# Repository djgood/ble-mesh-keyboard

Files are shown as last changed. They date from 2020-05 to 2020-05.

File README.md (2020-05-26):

# BLE Split Keyboard Project

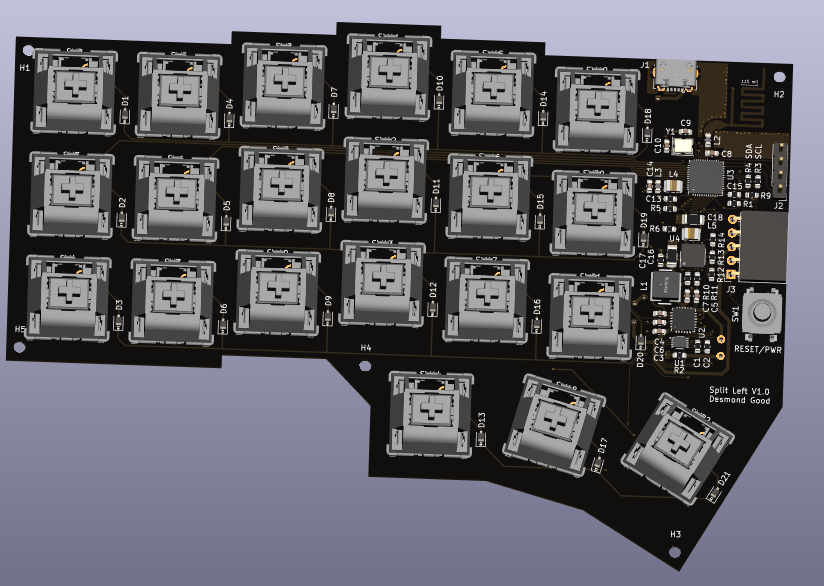
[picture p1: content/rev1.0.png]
rev1.0 layout


## Project Structure

    ├── doc             # datasheets, app notes, references
    ├── firmware        # Zephyr project files (TODO)
    ├── hardware        # KiCAD project files 

## Block Diagram

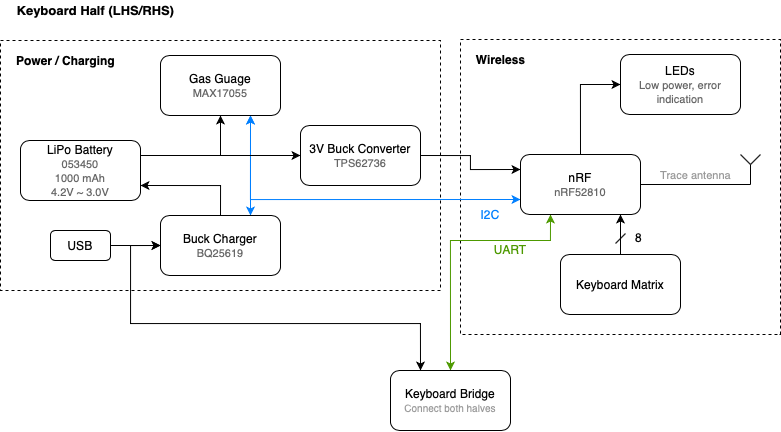
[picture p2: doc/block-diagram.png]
block diagram


View this project on [CADLAB.io](https://cadlab.io/project/22910).

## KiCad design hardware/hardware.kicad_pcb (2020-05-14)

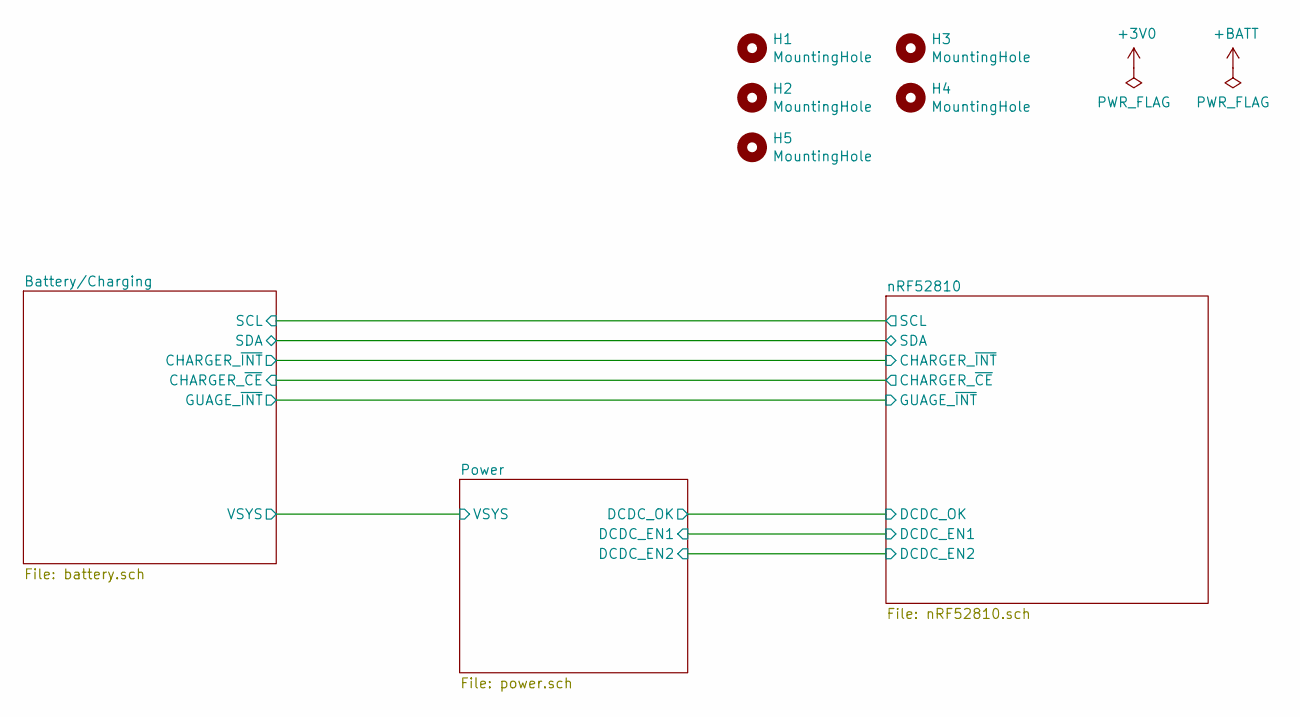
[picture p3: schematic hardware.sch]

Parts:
H1, H2, H3, H4, H5: MountingHole; MountingHole_2.2mm_M2

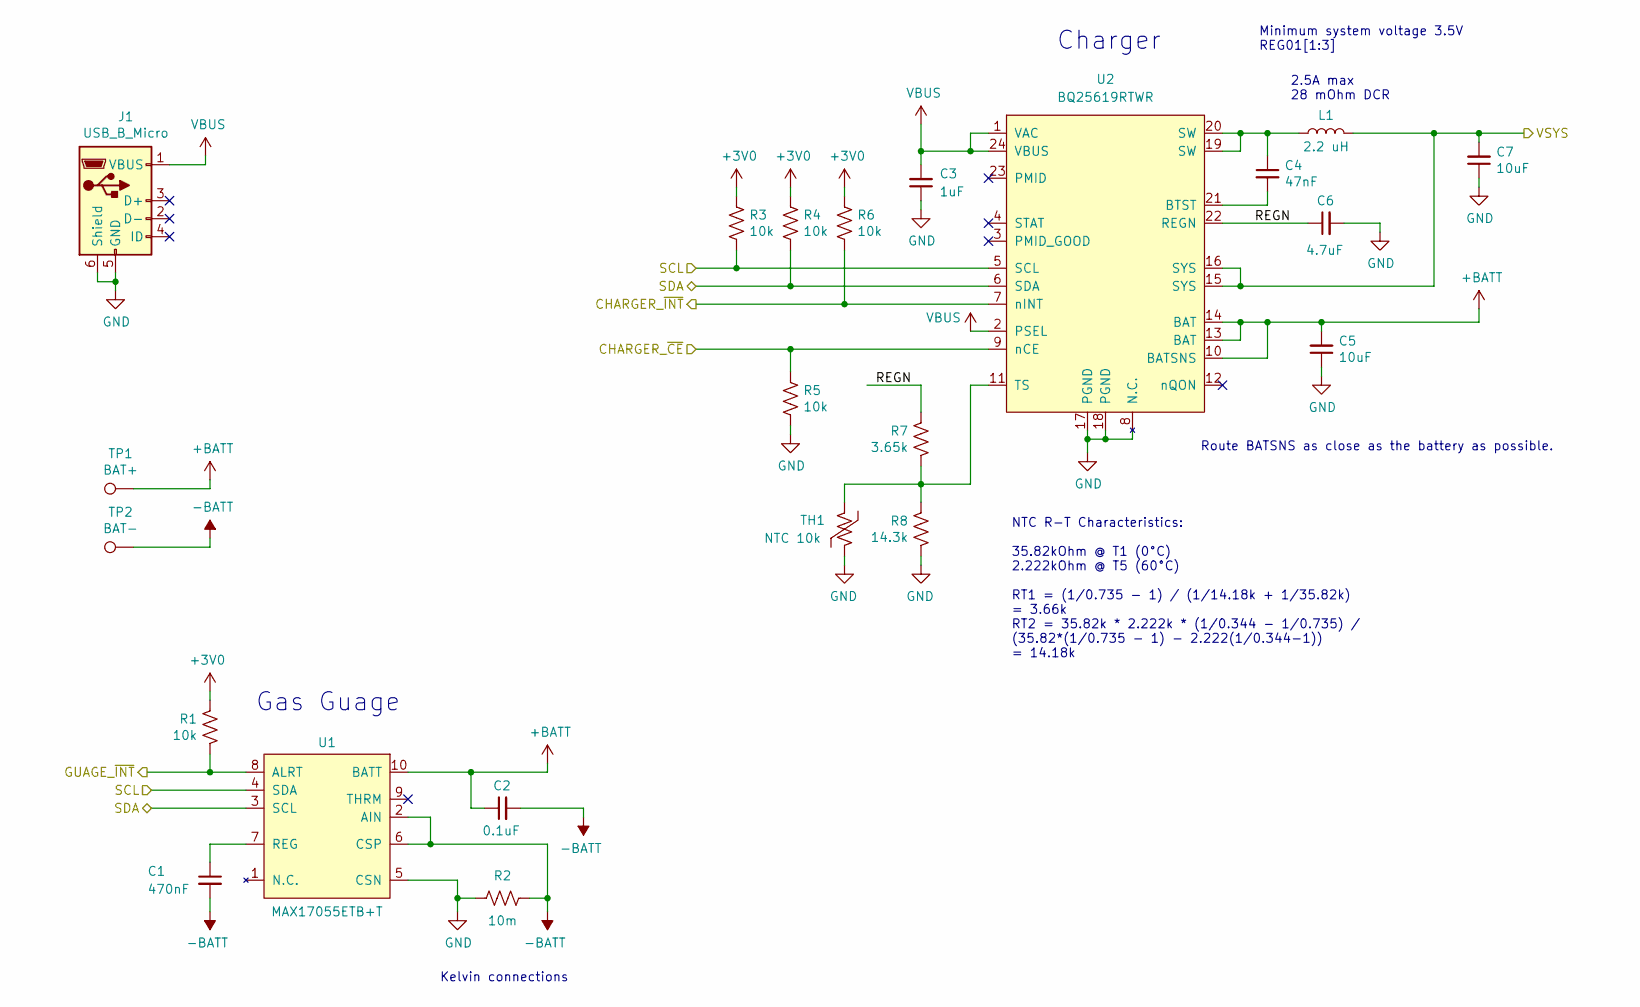
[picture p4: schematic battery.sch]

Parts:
C1: 470nF; R_0603_1608Metric; Part Number C0603C474K4RACTU
C2: 0.1uF; R_0603_1608Metric; Part Number C0603C104M4RACTU
C3: 1uF; C_0603_1608Metric; Part Number C0603C105K8PACTU
C4: 47nF; C_0603_1608Metric; Part Number C0603C473K4RACTU
C5, C7: 10uF; C_0603_1608Metric; Part Number GRM188R61A106KE69J
C6: 4.7uF; C_0603_1608Metric; Part Number C0603C475K9PACTU
J1: USB_B_Micro; USB_Micro-B_Molex-105017-0001; Part Number 1050171001
L1: 2.2 uH; WE-TPC4828; Part Number 7440430022
R1, R3, R4, R5, R6: 10k; R_0603_1608Metric; Part Number RC0603FR-0710KL
R2: 10m; R_0603_1608Metric; Part Number RL0816T-R010-F
R7: 3.65k; R_0603_1608Metric; Part Number RC0603FR-073K65L
R8: 14.3k; R_0603_1608Metric; Part Number RC0603FR-0714K3L
TH1: NTC 10k; R_0603_1608Metric; Part Number ERT-J1VR103J
TP1: BAT+; TestPoint_THTPad_D1.5mm_Drill0.7mm
TP2: BAT-; TestPoint_THTPad_D1.5mm_Drill0.7mm
U1: MAX17055ETB+T; TDFN-10-1EP_2.05mmx2.55mm_P0.4mm; Part Number MAX17055ETB+T
U2: BQ25619RTWR; Texas_S-PWQFN-N24_EP2.7x2.7mm; Part Number BQ25619RTWR

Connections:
+3V0: R1.1, R3.1, R4.1, R6.1; also elsewhere on the board
+BATT: C2.1, C5.2, TP1.1, U1.10 (BATT), U2.10 (BATSNS), U2.13 (BAT), U2.14 (BAT)
-BATT: C1.2, C2.2, R2.1, TP2.1, U1.2 (AIN), U1.6 (CSP), U1.11 (GND)
/Battery/Charging/CHARGER_~CE: R5.1, U2.9 (nCE); also elsewhere on the board
/Battery/Charging/CHARGER_~INT: R6.2, U2.7 (nINT); also elsewhere on the board
/Battery/Charging/GUAGE_~INT: R1.2, U1.8 (ALRT); also elsewhere on the board
/Battery/Charging/REGN: C6.1, R7.1, U2.22 (REGN)
/Battery/Charging/SCL: R3.2, U1.4 (SDA), U2.5 (SCL); also elsewhere on the board
/Battery/Charging/SDA: R4.2, U1.3 (SCL), U2.6 (SDA); also elsewhere on the board
/Battery/Charging/VSYS: C7.2, L1.2, U2.15 (SYS), U2.16 (SYS); also elsewhere on the board
GND: C3.1, C5.1, C6.2, C7.1, J1.5 (GND), J1.6 (Shield), R2.2, R5.2, R8.2, TH1.2, U1.5 (CSN), U2.8 (N.C.), U2.17 (PGND), U2.18 (PGND), U2.25 (GND); also elsewhere on the board
unnamed: C1.1, U1.7 (REG)
unnamed: C4.1, L1.1, U2.19 (SW), U2.20 (SW)
unnamed: C4.2, U2.21 (BTST)
unnamed: R7.2, R8.1, TH1.1, U2.11 (TS)
VBUS: C3.2, J1.1 (VBUS), U2.1 (VAC), U2.2 (PSEL), U2.24 (VBUS); also elsewhere on the board

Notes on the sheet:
Route BATSNS as close as the battery as possible.
NTC R-T Characteristics: 35.82kOhm @ T1 (0°C) 2.222kOhm @ T5 (60°C) RT1 = (1/0.735 - 1) / (1/14.18k + 1/35.82k) = 3.66k RT2 = 35.82k * 2.222k * (1/0.344 - 1/0.735) / (35.82*(1/0.735 - 1) - 2.222(1/0.344-1)) = 14.18k
2.5A max 28 mOhm DCR
Minimum system voltage 3.5V REG01[1:3]
Kelvin connections
Charger
Gas Guage

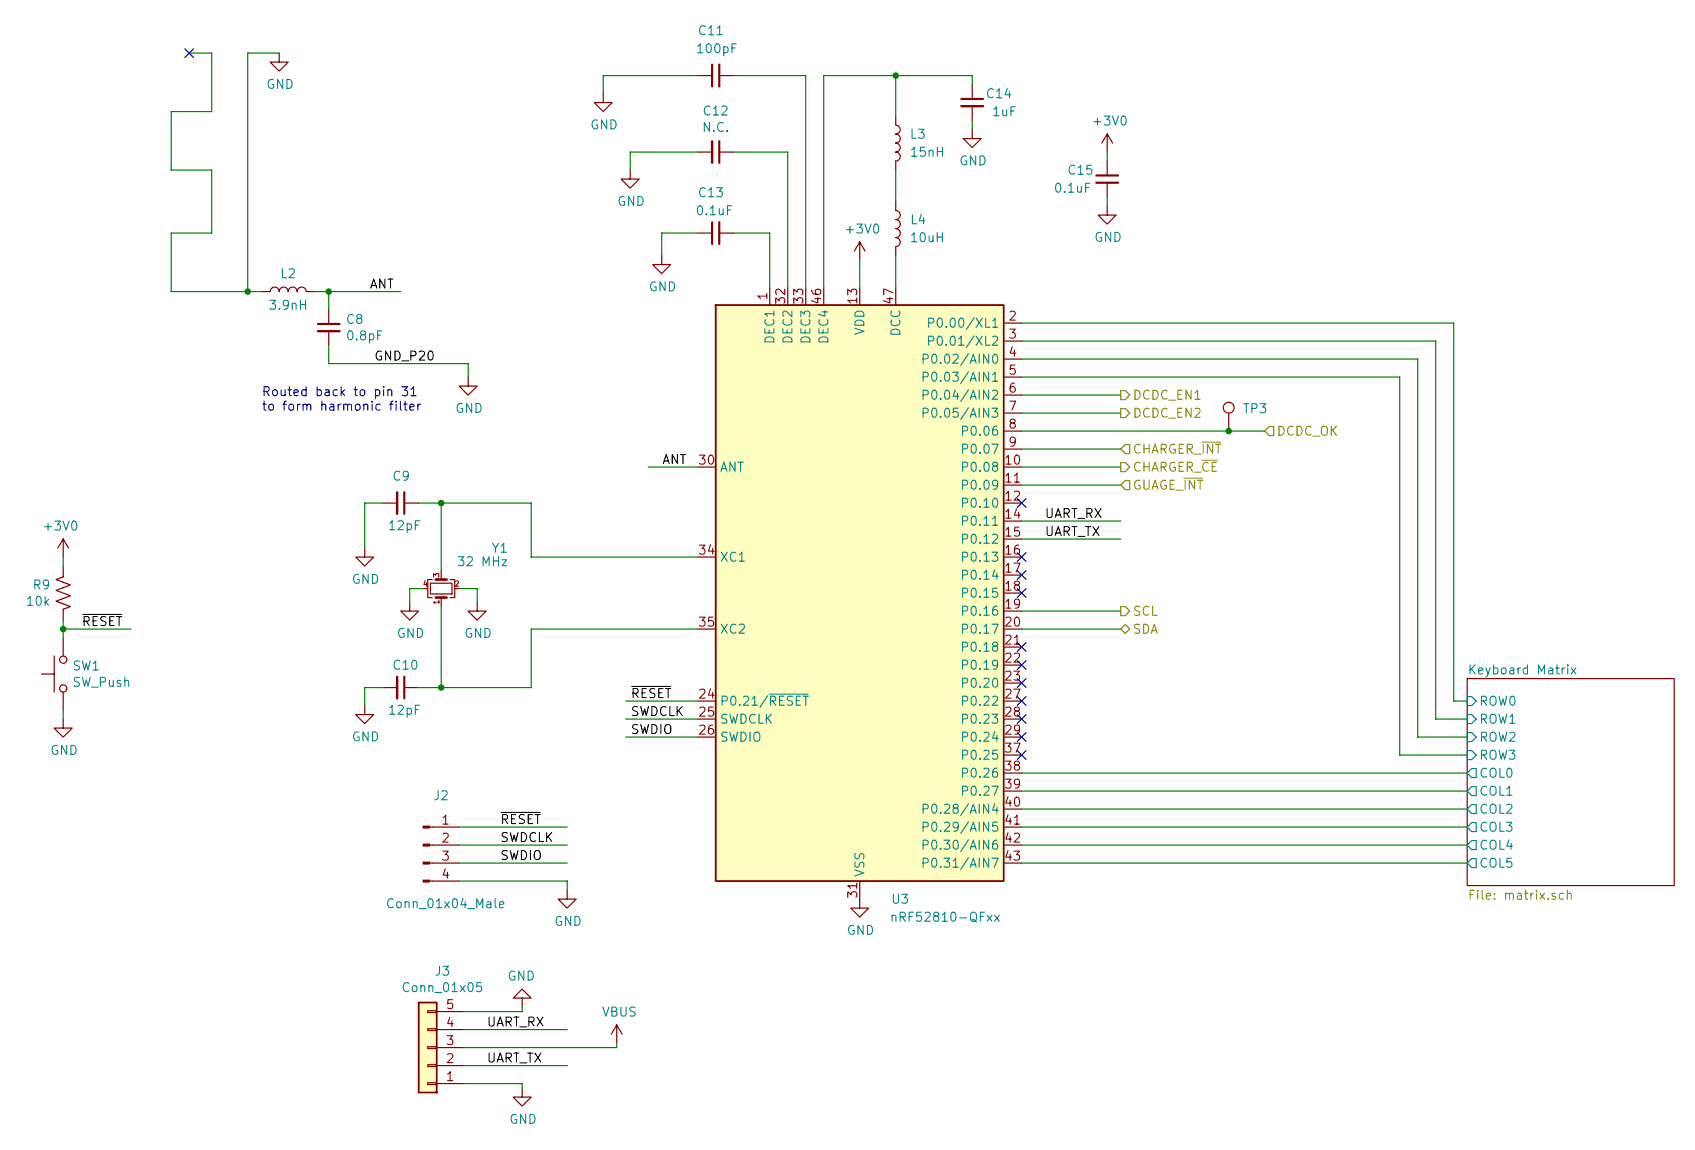
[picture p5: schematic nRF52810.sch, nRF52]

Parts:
C8: 0.8pF; C_0603_1608Metric; Part Number CBR06C808B5GAC
C9, C10: 12pF; C_0603_1608Metric; Part Number C0603C120J5GACTU
C11: 100pF; C_0603_1608Metric; Part Number C0603C101K5RACTU
C12: N.C.; R_0603_1608Metric
C13, C15: 0.1uF; R_0603_1608Metric; Part Number C0603C104M4RACTU
C14: 1uF; C_0603_1608Metric; Part Number C0603C105K8PACTU
J2: Conn_01x04_Male; PinHeader_1x04_P2.54mm_Vertical; Part Number 68000-104HLF
J3: Conn_01x05; PinSocket_1x05_P2.54mm_Horizontal; Part Number PPPC051LGBN-RC
L2: 3.9nH; L_0603_1608Metric; Part Number LQW18AN3N9D00D
L3: 15nH; L_0603_1608Metric; Part Number LQW18AN15NG00D
L4: 10uH; L_1008_2520Metric; Part Number DFE252012C-H-100M
R9: 10k; R_0603_1608Metric; Part Number RC0603FR-0710KL
SW1: SW_Push; SW_SPST_B3S-1000; Part Number B3S-1000P
TP3: TP_DCDC_OK; TestPoint_Pad_D1.0mm
U3: nRF52810-QFxx; QFN-48-1EP_6x6mm_P0.4mm_EP4.6x4.6mm; Part Number NRF52810-QFAA-R7
Y1: 32 MHz; Crystal_SMD_Abracon_ABM8G-4Pin_3.2x2.5mm; Part Number ABM8G-32.000MHZ-B4Y-T

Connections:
+3V0: C15.1, R9.1, U3.13 (VDD), U3.36 (VDD), U3.48 (VDD); also elsewhere on the board
/Battery/Charging/CHARGER_~CE: U3.10 (P0.08); also elsewhere on the board
/Battery/Charging/CHARGER_~INT: U3.9 (P0.07); also elsewhere on the board
/Battery/Charging/GUAGE_~INT: U3.11 (P0.09); also elsewhere on the board
/Battery/Charging/SCL: U3.19 (P0.16); also elsewhere on the board
/Battery/Charging/SDA: U3.20 (P0.17); also elsewhere on the board
/Power/DCDC_EN1: U3.6 (P0.04/AIN2); also elsewhere on the board
/Power/DCDC_EN2: U3.7 (P0.05/AIN3); also elsewhere on the board
/Power/DCDC_OK: TP3.1, U3.8 (P0.06); also elsewhere on the board
/nRF52810/ANT: C8.1, L2.2, U3.30 (ANT)
/nRF52810/Keyboard Matrix/COL0: U3.38 (P0.26); also elsewhere on the board
/nRF52810/Keyboard Matrix/COL1: U3.39 (P0.27); also elsewhere on the board
/nRF52810/Keyboard Matrix/COL2: U3.40 (P0.28/AIN4); also elsewhere on the board
/nRF52810/Keyboard Matrix/COL3: U3.41 (P0.29/AIN5); also elsewhere on the board
/nRF52810/Keyboard Matrix/COL4: U3.42 (P0.30/AIN6); also elsewhere on the board
/nRF52810/Keyboard Matrix/COL5: U3.43 (P0.31/AIN7); also elsewhere on the board
/nRF52810/Keyboard Matrix/ROW0: U3.2 (P0.00/XL1); also elsewhere on the board
/nRF52810/Keyboard Matrix/ROW1: U3.3 (P0.01/XL2); also elsewhere on the board
/nRF52810/Keyboard Matrix/ROW2: U3.4 (P0.02/AIN0); also elsewhere on the board
/nRF52810/Keyboard Matrix/ROW3: U3.5 (P0.03/AIN1); also elsewhere on the board
/nRF52810/SWDCLK: J2.2, U3.25 (SWDCLK)
/nRF52810/SWDIO: J2.3, U3.26 (SWDIO)
/nRF52810/UART_RX: J3.4, U3.14 (P0.11)
/nRF52810/UART_TX: J3.2, U3.15 (P0.12)
/nRF52810/~RESET: J2.1, R9.2, SW1.2, U3.24 (P0.21/~RESET)
GND: C8.2, C9.2, C10.2, C11.1, C12.2, C13.1, C14.2, C15.2, J2.4, J3.1, J3.5, L2.1, SW1.1, U3.31 (VSS), U3.45 (VSS), U3.49 (VSS), Y1.2, Y1.4; also elsewhere on the board
unnamed: C9.1, U3.34 (XC1), Y1.3
unnamed: C10.1, U3.35 (XC2), Y1.1
unnamed: C11.2, U3.33 (DEC3)
unnamed: C12.1, U3.32 (DEC2)
unnamed: C13.2, U3.1 (DEC1)
unnamed: C14.1, L3.1, U3.46 (DEC4)
unnamed: L3.2, L4.1
unnamed: L4.2, U3.47 (DCC)
VBUS: J3.3; also elsewhere on the board

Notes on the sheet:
Routed back to pin 31 to form harmonic filter

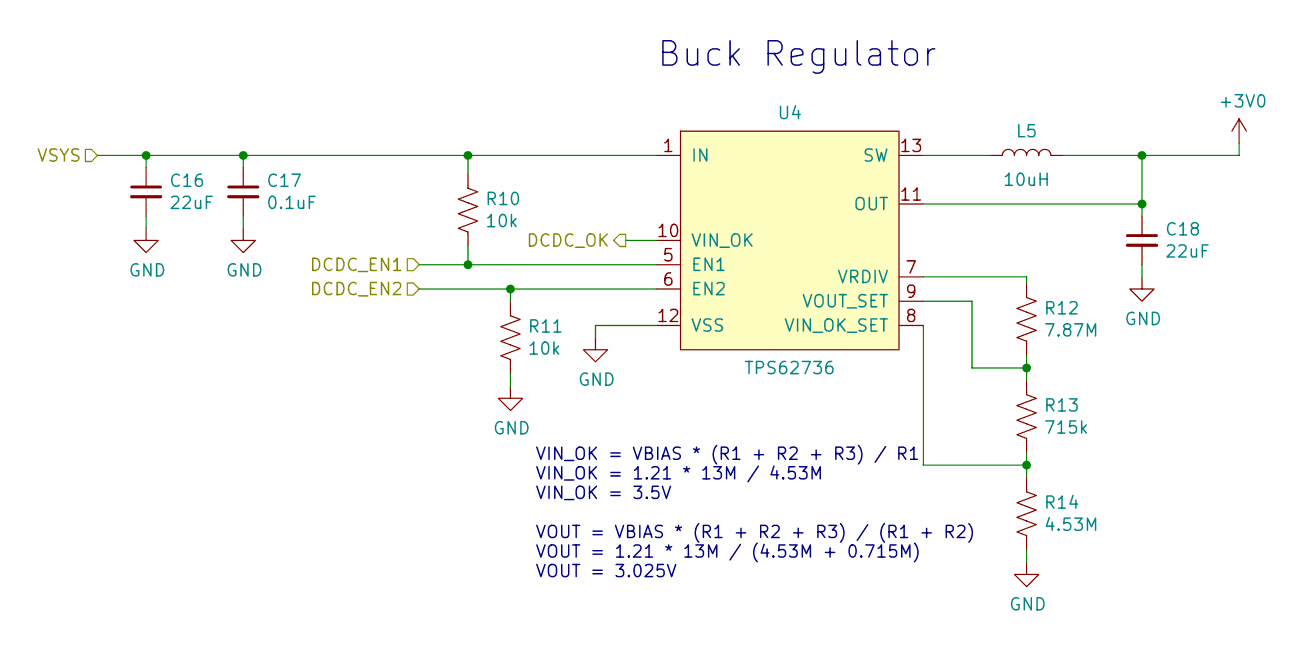
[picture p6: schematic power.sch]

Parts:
C16, C18: 22uF; R_1206_3216Metric; Part Number C1206C226M8RACTU
C17: 0.1uF; R_0603_1608Metric; Part Number C0603C104M4RACTU
L5: 10uH; L_1008_2520Metric; Part Number DFE252012C-H-100M
R10, R11: 10k; R_0603_1608Metric; Part Number RC0603FR-0710KL
R12: 7.87M; R_0603_1608Metric; Part Number RMCF0603FT7M87
R13: 715k; R_0603_1608Metric; Part Number RC0603FR-071KL
R14: 4.53M; R_0603_1608Metric; Part Number CRCW06034M53FKEA
U4: TPS62736; Texas_S-PVQFN-N14; Part Number TPS62736RGYR

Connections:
+3V0: C18.1, L5.2, U4.11 (OUT); also elsewhere on the board
/Battery/Charging/VSYS: C16.1, C17.1, R10.1, U4.1 (IN); also elsewhere on the board
/Power/DCDC_EN1: R10.2, U4.5 (EN1); also elsewhere on the board
/Power/DCDC_EN2: R11.1, U4.6 (EN2); also elsewhere on the board
/Power/DCDC_OK: U4.10 (VIN_OK); also elsewhere on the board
GND: C16.2, C17.2, C18.2, R11.2, R14.2, U4.2 (NC), U4.3 (NC), U4.4 (NC), U4.12 (VSS), U4.14 (NC), U4.15 (PAD); also elsewhere on the board
unnamed: L5.1, U4.13 (SW)
unnamed: R12.1, U4.7 (VRDIV)
unnamed: R12.2, R13.1, U4.9 (VOUT_SET)
unnamed: R13.2, R14.1, U4.8 (VIN_OK_SET)

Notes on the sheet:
VIN_OK = VBIAS * (R1 + R2 + R3) / R1 VIN_OK = 1.21 * 13M / 4.53M VIN_OK = 3.5V VOUT = VBIAS * (R1 + R2 + R3) / (R1 + R2) VOUT = 1.21 * 13M / (4.53M + 0.715M) VOUT = 3.025V
Buck Regulator

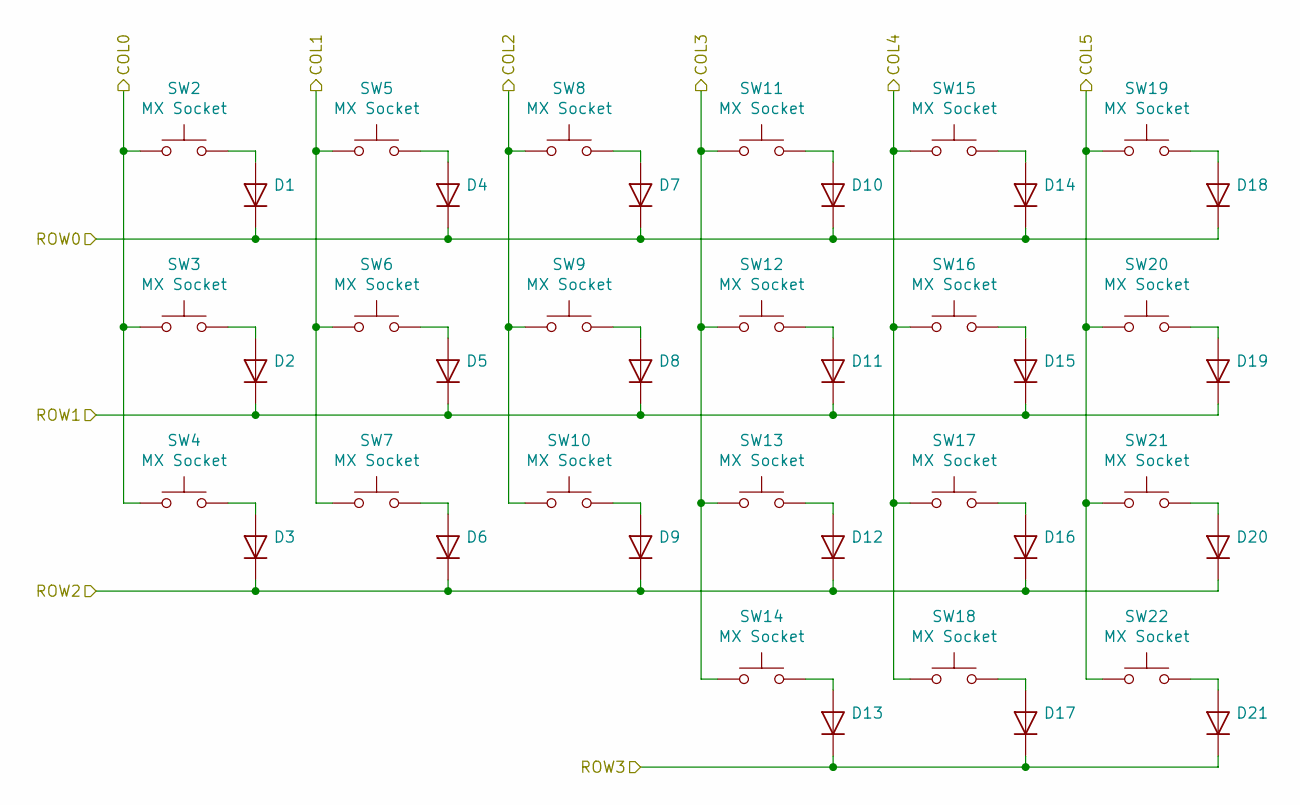
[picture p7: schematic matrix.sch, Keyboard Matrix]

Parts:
D1, D2, D3, D4, D5, D6, D7, D8, D9, D10, D11, D12, D13, D14, D15, D16, D17, D18, D19, D20, D21: 1N4148WSTR; D_SOD-323; Part Number 1N4148WSTR
SW2, SW3, SW4, SW5, SW6, SW7, SW8, SW9, SW10, SW11, SW12, SW13, SW14, SW15, SW16, SW17, SW18, SW19, SW20, SW21, SW22: MX Socket; Kailh_socket_MX_optional; Part Number CPG151101S11

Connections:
/nRF52810/Keyboard Matrix/COL0: SW2.1, SW3.1, SW4.1; also elsewhere on the board
/nRF52810/Keyboard Matrix/COL1: SW5.1, SW6.1, SW7.1; also elsewhere on the board
/nRF52810/Keyboard Matrix/COL2: SW8.1, SW9.1, SW10.1; also elsewhere on the board
/nRF52810/Keyboard Matrix/COL3: SW11.1, SW12.1, SW13.1, SW14.1; also elsewhere on the board
/nRF52810/Keyboard Matrix/COL4: SW15.1, SW16.1, SW17.1, SW18.1; also elsewhere on the board
/nRF52810/Keyboard Matrix/COL5: SW19.1, SW20.1, SW21.1, SW22.1; also elsewhere on the board
/nRF52810/Keyboard Matrix/ROW0: D1.1 (K), D4.1 (K), D7.1 (K), D10.1 (K), D14.1 (K), D18.1 (K); also elsewhere on the board
/nRF52810/Keyboard Matrix/ROW1: D2.1 (K), D5.1 (K), D8.1 (K), D11.1 (K), D15.1 (K), D19.1 (K); also elsewhere on the board
/nRF52810/Keyboard Matrix/ROW2: D3.1 (K), D6.1 (K), D9.1 (K), D12.1 (K), D16.1 (K), D20.1 (K); also elsewhere on the board
/nRF52810/Keyboard Matrix/ROW3: D13.1 (K), D17.1 (K), D21.1 (K); also elsewhere on the board
unnamed: D1.2 (A), SW2.2
unnamed: D2.2 (A), SW3.2
unnamed: D3.2 (A), SW4.2
unnamed: D4.2 (A), SW5.2
unnamed: D5.2 (A), SW6.2
unnamed: D6.2 (A), SW7.2
unnamed: D7.2 (A), SW8.2
unnamed: D8.2 (A), SW9.2
unnamed: D9.2 (A), SW10.2
unnamed: D10.2 (A), SW11.2
unnamed: D11.2 (A), SW12.2
unnamed: D12.2 (A), SW13.2
unnamed: D13.2 (A), SW14.2
unnamed: D14.2 (A), SW15.2
unnamed: D15.2 (A), SW16.2
unnamed: D16.2 (A), SW17.2
unnamed: D17.2 (A), SW18.2
unnamed: D18.2 (A), SW19.2
unnamed: D19.2 (A), SW20.2
unnamed: D20.2 (A), SW21.2
unnamed: D21.2 (A), SW22.2

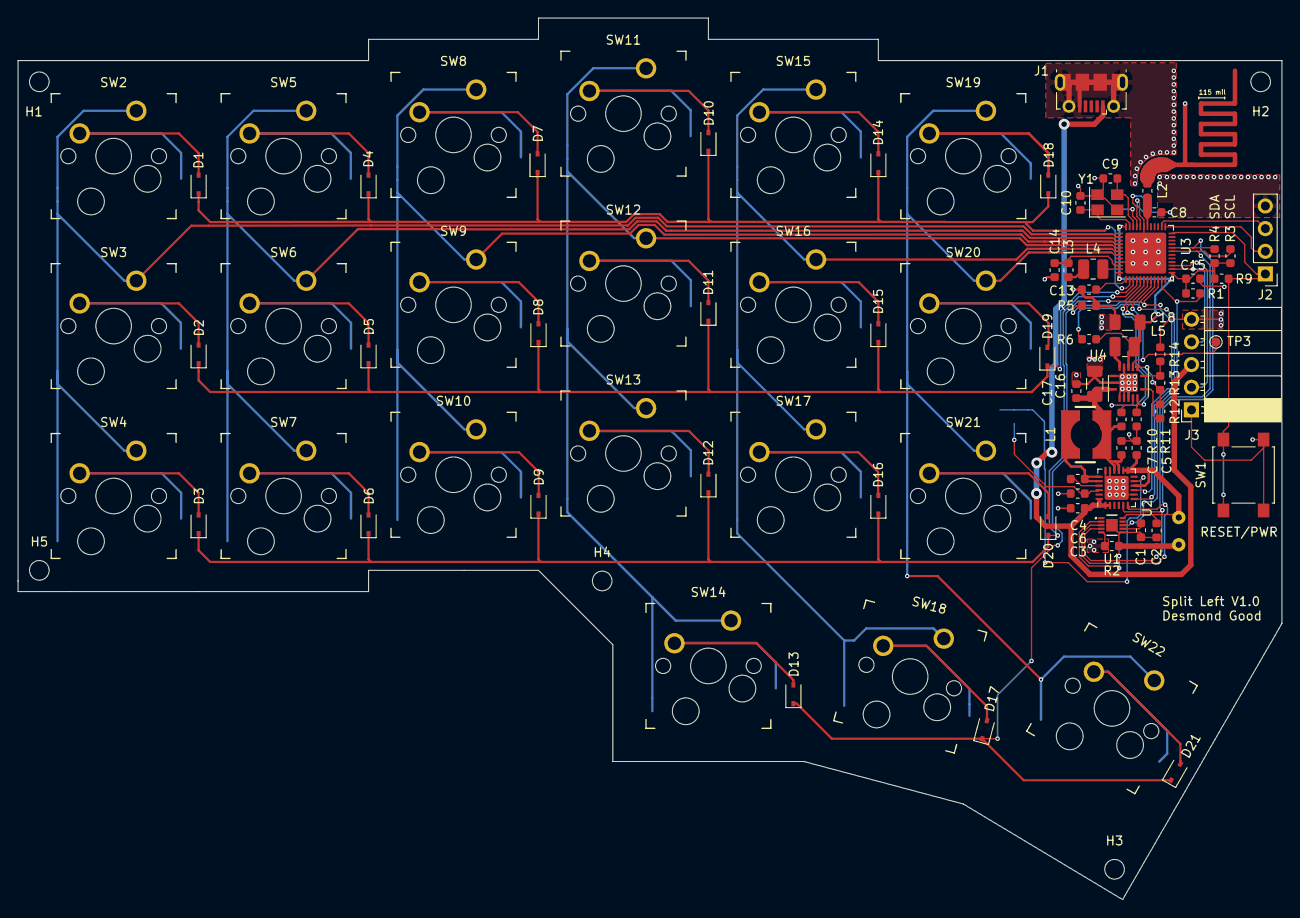
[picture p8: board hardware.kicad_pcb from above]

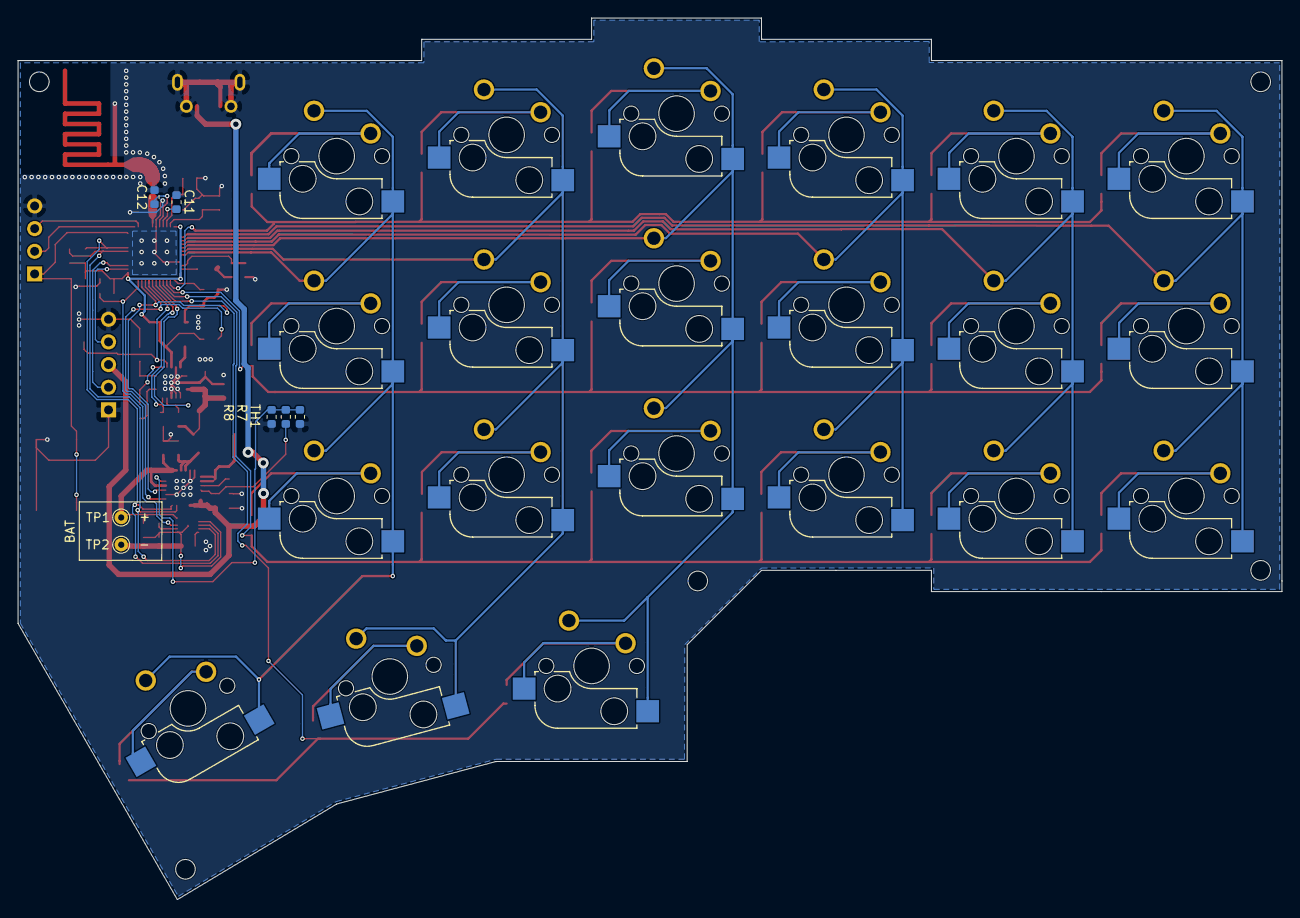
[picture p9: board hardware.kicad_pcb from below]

Board: 2 copper layers, 141.7 x 98.8 mm, 97 parts (7 on the bottom side), 68 nets.

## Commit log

2020-05-14 Initial prototype of keyboard
    [battery.sch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]
2020-05-14 Remove *.sch-bak and *.kicad_pcb-bak files
2020-05-17 Update the part number for R13
    The part number was specified as `603-RC0603FR-071KL` but should have
    been `RC0603FR-07715KL`. The part number in the schematic has been
    updated to reflect this.
    [power.sch]
2020-05-18 Invert pull-up/down supply for R10, R11
    The voltage for these resistors was wrong, so the 3V buck was configured
    to be in ship mode by default.
    The 3V buck will now start in enable mode with the following
    configuration:
    - R10 (EN2) = 1
    - R11 (EN1) = 0
    [power.sch]
2020-05-25 Add PCB and block diagram to README.md

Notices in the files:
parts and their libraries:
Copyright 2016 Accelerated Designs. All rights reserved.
